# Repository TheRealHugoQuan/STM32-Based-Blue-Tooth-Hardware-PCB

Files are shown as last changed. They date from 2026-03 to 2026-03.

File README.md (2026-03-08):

# 📡 STM32 Bluetooth Low Energy (BLE) Node

## 📖 Overview
This repository contains the complete hardware design files (schematic and PCB layout) for a custom Bluetooth Low Energy (BLE) development board powered by the STM32 architecture. 

Designed specifically for [e.g., low-power IoT applications / wearable prototyping], this board integrates a high-performance ARM Cortex-M core with a 2.4GHz RF radio, optimized power routing, and exposed peripheral headers for rapid sensor integration.

## 🛠️ Hardware Specifications
* **Microcontroller:** [e.g., STM32WB55RG / STM32F4 + External NRF module]
* **Wireless Protocol:** Bluetooth Low Energy (BLE) [e.g., 5.2]
* **Antenna Design:** [e.g., 2.4GHz Meandering PCB Trace Antenna / U.FL connector for external antenna]
* **Clock/Oscillators:** * High-Speed External (HSE): [e.g., 32 MHz crystal for RF timing]
  * Low-Speed External (LSE): [e.g., 32.768 kHz crystal for RTC/Low Power modes]
* **Power Supply:** [e.g., 3.3V LDO regulated from a 5V USB-C input or single Li-Po cell]
* **Programming Interface:** Standard 10-pin SWD (Serial Wire Debug) header
* **Dimensions:** [e.g., 40mm x 25mm]
* **Layers:** [e.g., 4-Layer FR4 with dedicated continuous ground plane for RF shielding]

## 📁 Repository Structure
* `/hardware/` - Core KiCad project files (`.kicad_pro`, `.kicad_sch`, `.kicad_pcb`).
* `/fabrication/` - Exported Gerber files, drill files, and BOM/CPL files ready for PCB assembly (PCBA).
* `/firmware/` - Placeholder or link to the accompanying STM32CubeIDE / Zephyr RTOS software repository.
* `/datasheets/` - Critical component datasheets (MCU, Antenna matching components).

## 🚀 Getting Started
To view or

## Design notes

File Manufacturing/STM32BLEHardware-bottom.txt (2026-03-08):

### Footprint positions - created on 2026-01-26T21:31:32-0500 ###
### Printed by KiCad version 9.0.7
## Unit = mm, Angle = deg.
## Side : bottom
# Ref     Val       Package                PosX       PosY       Rot  Side
## End

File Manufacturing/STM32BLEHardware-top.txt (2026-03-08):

### Footprint positions - created on 2026-01-26T21:31:32-0500 ###
### Printed by KiCad version 9.0.7
## Unit = mm, Angle = deg.
## Side : top
# Ref     Val                          Package                                                       PosX       PosY       Rot  Side
C1        4u7                          C_0603_1608Metric                                          28.2500    12.0250  -90.0000  top
C2        100n                         C_0402_1005Metric                                          30.8000    12.2700  -90.0000  top
C3        100n                         C_0402_1005Metric                                          40.4000    15.6200  -90.0000  top
C4        100n                         C_0402_1005Metric                                          32.6700    20.5500  180.0000  top
C5        100n                         C_0402_1005Metric                                          29.6500    12.2400  -90.0000  top
C6        100n                         C_0402_1005Metric                                          37.8000    10.3700  -90.0000  top
C7        4u7                          C_0603_1608Metric                                          32.0250    23.1000  180.0000  top
C8        100n                         C_0402_1005Metric                                          32.6700    21.7000  180.0000  top
C9        100n                         C_0402_1005Metric                                          40.7000    18.3700  -90.0000  top
C10       4u7                          C_0603_1608Metric                                          37.3750    21.2500    0.0000  top
C11       C                            C_0402_1005Metric                                          32.4000    10.7000  180.0000  top
C12       C                            C_0402_1005Metric                                          34.5000    10.7000    0.0000  top
C13       0p8                          C_0402_1005Metric                                          41.6500    16.3700  -90.0000  top
C14       0p3                          C_0402_1005Metric                                          44.7600    16.4200  -90.0000  top
C15       100n                         C_0402_1005Metric                                          21.3200    10.3500  180.0000  top
C16       100n                         C_0402_1005Metric                                          54.8500    10.1700  -90.0000  top
C17       4u7                          C_0603_1608Metric                                           9.9000    11.3750  -90.0000  top
C18       4u7                          C_0603_1608Metric                                          15.9500    11.4000  -90.0000  top
C19       100n                         C_0402_1005Metric                                          30.2200    16.9000  180.0000  top
D1        LED                          LED_0402_1005Metric                                        30.3150    14.0000    0.0000  top
FID1      Fiducial                     Fiducial_1mm_Mask2mm                                        7.8500     2.4000    0.0000  top
FID2      Fiducial                     Fiducial_1mm_Mask2mm                                       51.2000    23.6000    0.0000  top
FID3      Fiducial                     Fiducial_1mm_Mask2mm                                       51.2000     2.1000    0.0000  top
FLT1      DLF162500LT-5028A1           Untitled                                                   46.5500    16.9300    0.0000  top
J1        Conn_Coaxial                 U.FL_Hirose_U.FL-R-SMT-1_Vertical                          49.8700    16.8000    0.0000  top
J3        USB_C_Receptacle_USB2.0_16P  USB_C_Receptacle_GCT_USB4105-xx-A_16P_TopMnt_Horizontal     4.0600    14.5500  -90.0000  top
J4        Conn_01x04_Pin               Molex_PicoBlade_53048-0410_1x04_P1.25mm_Horizontal         36.9250     4.8000    0.0000  top
L1        10u                          L_0805_2012Metric                                          35.4125    23.0000  180.0000  top
L2        10n                          L_0402_1005Metric                                          34.3500    20.9850   90.0000  top
L3        2n7                          L_0402_1005Metric                                          43.2250    16.8500  180.0000  top
R1        5k1                          R_0402_1005Metric                                          56.0000    10.1400  -90.0000  top
R2        220R                         R_0402_1005Metric                                          53.2400    10.6500    0.0000  top
R3        5k1                          R_0402_1005Metric                                           6.9600     8.5000    0.0000  top
R4        5k1                          R_0402_1005Metric                                           7.6500    20.9000  180.0000  top
R5        220R                         R_0402_1005Metric                                          39.0000    10.3400  -90.0000  top
R6        220R                         R_0402_1005Metric                                          40.1000    10.3400  -90.0000  top
R7        220R                         R_0402_1005Metric                                          28.0400    14.2000  180.0000  top
SW1       SW_Push                      SW_SPST_CK_RS282G05A3                                      47.2000    10.7000    0.0000  top
U1        STM32WB55CEU6                QFN-48-1EP_7x7mm_P0.5mm_EP5.6x5.6mm                        35.6000    15.6500   90.0000  top
U2        USBLC6-2SC6(ESD)             SOT-23-6                                                   13.8125    18.7000    0.0000  top
U3        MIC5365-3.3YD5               TSOT-23-5                                                  13.0125    11.2500    0.0000  top
Y1        32MHz                        Crystal_SMD_2016-4Pin_2.0x1.6mm                            40.8000    21.4000   90.0000  top
Y2        32kHz768                     Crystal_SMD_2012-2Pin_2.0x1.2mm                            33.1000     8.3500    0.0000  top
## End

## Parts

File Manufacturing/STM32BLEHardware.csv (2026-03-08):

Reference | Qty | Value | DNP | Exclude from BOM | Exclude from Board | Footprint | Datasheet | Manufacturer | Manufacturer Part No. | Link
C1,C7,C10,C17,C18 | 5 | 4u7 |  |  |  | Capacitor_SMD:C_0603_1608Metric | ~ | KYOCERA AVX | 0603ZD475KAT2A | https://www.google.com/search
C2,C3,C4,C5,C6,C8,C9,C15,C16,C19 | 10 | 100n |  |  |  | Capacitor_SMD:C_0402_1005Metric | ~ | KYOCERA AVX | VX 0402ZC104KAT2A | https://www.google.com/search
C11,C12 | 2 | C |  |  |  | Capacitor_SMD:C_0402_1005Metric | ~ | KYOCERA AVX | 04025A120JAT2A | https://www.google.com/search
C13 | 1 | 0p8 |  |  |  | Capacitor_SMD:C_0402_1005Metric | ~ | Murata | GJM1555C1HR80WB01D | https://www.google.com/search
C14 | 1 | 0p3 |  |  |  | Capacitor_SMD:C_0402_1005Metric | ~ | Murata | GJM1555C1HR30WB01D | https://www.google.com/search
D1 | 1 | LED |  |  |  | LED_SMD:LED_0402_1005Metric | ~ | Wurth Elektronik | 150040GS73220 | https://www.google.com/search
FID1,FID2,FID3 | 3 | Fiducial |  | Excluded from BOM |  | Fiducial:Fiducial_1mm_Mask2mm | ~
FLT1 | 1 | DLF162500LT-5028A1 |  |  |  | myFootPrint:Untitled |  | TDK | DLF162500LT-5028A1 | https://www.google.com/search?q=https://www.mouser.com/ProductDetail/TDK/DLF162500LT-5028A1
H1,H2,H3,H4 | 4 | MountingHole_Pad |  | Excluded from BOM |  | MountingHole:MountingHole_2.2mm_M2_Pad_Via | ~
J1 | 1 | Conn_Coaxial |  |  |  | Connector_Coaxial:U.FL_Hirose_U.FL-R-SMT-1_Vertical | ~ | Hirose | U.FL-R-SMT-1(10) | https://www.google.com/search
J2 | 1 | Conn_ARM_SWD_TagConnect_TC2030 |  | Excluded from BOM |  | Connector:Tag-Connect_TC2030-IDC-FP_2x03_P1.27mm_Vertical | https://www.tag-connect.com/wp-content/uploads/bsk-pdf-manager/TC2030-CTX_1.pdf | Tag-Connect | TC2030-IDC-NL (Cable) | https://www.tag-connect.com/product/tc2030-idc-nl
J3 | 1 | USB_C_Receptacle_USB2.0_16P |  |  |  | Connector_USB:USB_C_Receptacle_GCT_USB4105-xx-A_16P_TopMnt_Horizontal | https://www.usb.org/sites/default/files/documents/usb_type-c.zip | GCT | USB4105-GF-A | https://www.google.com/search
J4 | 1 | Conn_01x04_Pin |  |  |  | Connector_Molex:Molex_PicoBlade_53048-0410_1x04_P1.25mm_Horizontal | ~ | Molex | 53048-0410 | https://www.google.com/search?q=https://www.digikey.com/en/products/detail/molex/0530480410/252975
L1 | 1 | 10u |  |  |  | Inductor_SMD:L_0805_2012Metric | ~ | Murata | LQM21PN100MGR | https://www.google.com/search
L2 | 1 | 10n |  |  |  | Inductor_SMD:L_0402_1005Metric | ~ | Murata | LQG15HS10NJ02D | https://www.google.com/search
L3 | 1 | 2n7 |  |  |  | Inductor_SMD:L_0402_1005Metric | ~ | Murata | LQG15HS2N7S02D | https://www.google.com/search
R1,R3,R4 | 3 | 5k1 |  |  |  | Resistor_SMD:R_0402_1005Metric | ~ | Yageo | RC0402JR-075K1L | https://www.google.com/search
R2,R5,R6,R7 | 4 | 220R |  |  |  | Resistor_SMD:R_0402_1005Metric | ~ | Yageo | RC0402JR-07220RL | https://www.google.com/search
SW1 | 1 | SW_Push |  |  |  | Button_Switch_SMD:SW_SPST_CK_RS282G05A3 | ~ | C&K | RS-282G05A3-SM RT | https://www.google.com/search
U1 | 1 | STM32WB55CEU6 |  |  |  | Package_DFN_QFN:QFN-48-1EP_7x7mm_P0.5mm_EP5.6x5.6mm | https://www.st.com/resource/en/datasheet/stm32wb55ce.pdf | STMicroelectronics | STM32WB55CEU6 | https://www.google.com/search
U2 | 1 | USBLC6-2SC6(ESD) |  |  |  | Package_TO_SOT_SMD:SOT-23-6 | https://www.st.com/resource/en/datasheet/usblc6-2.pdf | STMicroelectronics | USBLC6-2SC6 | https://www.digikey.com/en/products/detail/microchip-technology/MIC5365-3-3YD5-TR/3671879
U3 | 1 | MIC5365-3.3YD5 |  |  |  | Package_TO_SOT_SMD:TSOT-23-5 | https://ww1.microchip.com/downloads/aemDocuments/documents/APID/ProductDocuments/DataSheets/MIC5365-6-High-Performance-Single-150mA-LDO-DS20006605A.pdf | Microchip | MIC5365-3.3YD5-TR | https://www.digikey.com/en/products/detail/microchip-technology/MIC5365-3-3YD5-TR/3671879
Y1 | 1 | 32MHz |  |  |  | Crystal:Crystal_SMD_2016-4Pin_2.0x1.6mm | ~ | NDK | NX2016SA-32M-EXS00A-CS06465 | https://www.google.com/search
Y2 | 1 | 32kHz768 |  |  |  | Crystal:Crystal_SMD_2012-2Pin_2.0x1.2mm | ~ | NDK | NX2012SA-32.768K-STD-MUB-1 | https://www.google.com/search

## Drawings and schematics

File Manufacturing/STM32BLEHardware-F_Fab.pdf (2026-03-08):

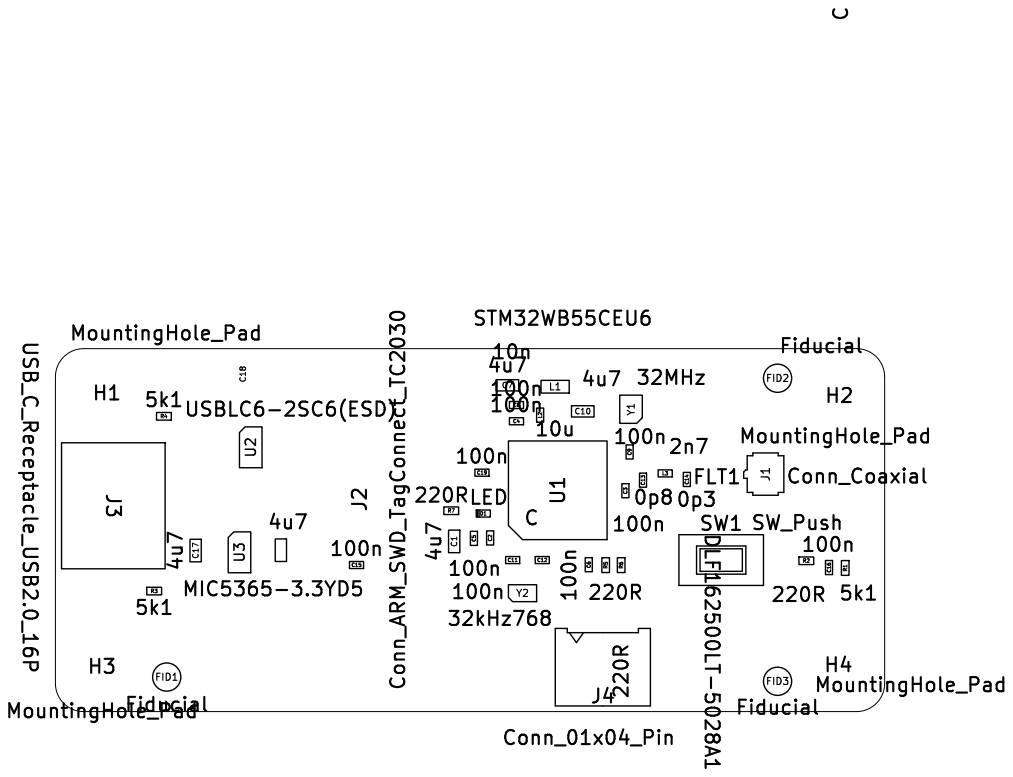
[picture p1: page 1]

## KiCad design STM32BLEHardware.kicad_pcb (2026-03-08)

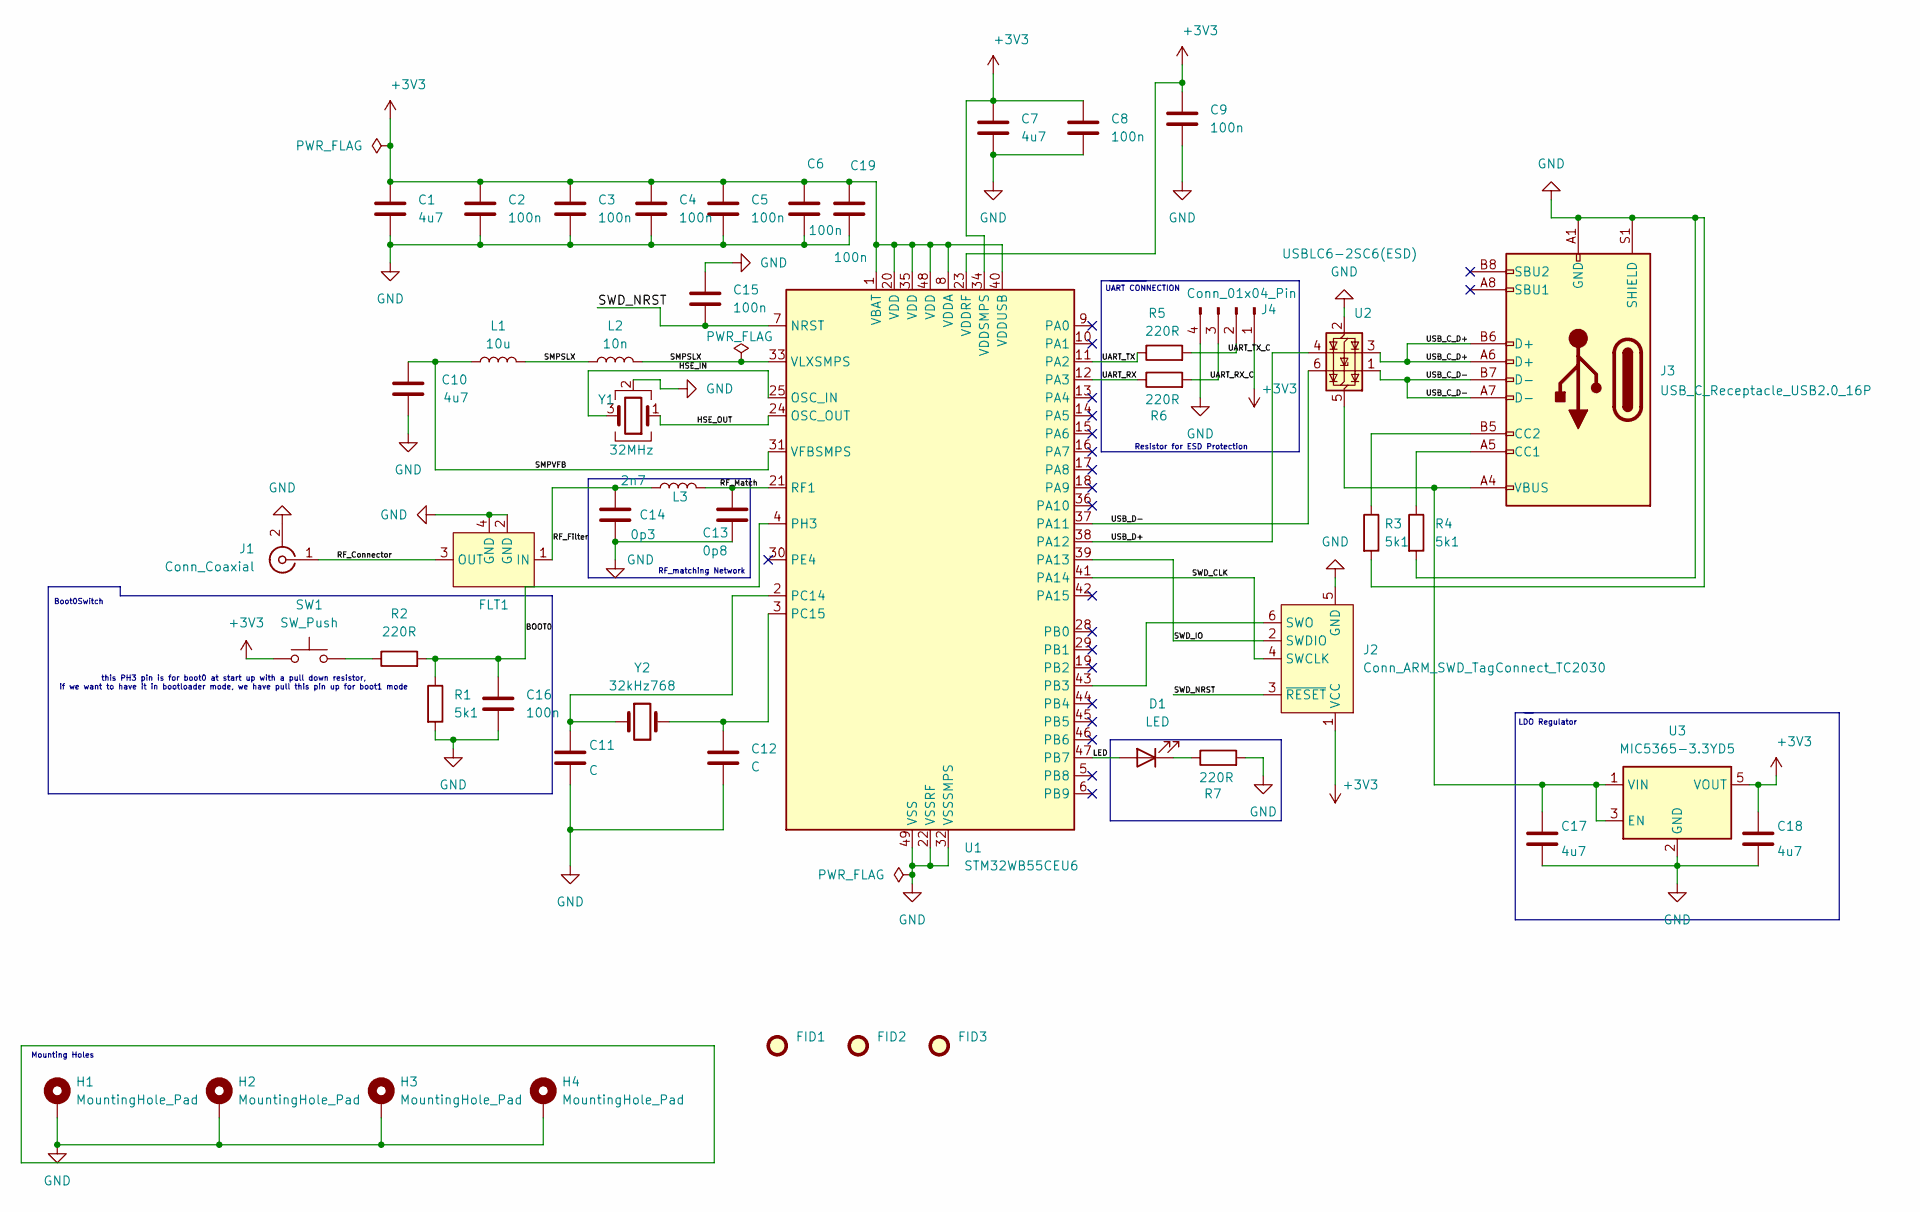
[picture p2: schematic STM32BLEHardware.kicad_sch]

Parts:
C1, C7, C10, C17, C18: 4u7; C_0603_1608Metric; Manufacturer Part No. 0603ZD475KAT2A
C2, C3, C4, C5, C6, C8, C9, C15, C16, C19: 100n; C_0402_1005Metric; Manufacturer Part No. VX 0402ZC104KAT2A
C11, C12: C; C_0402_1005Metric; Manufacturer Part No. 04025A120JAT2A
C13: 0p8; C_0402_1005Metric; Manufacturer Part No. GJM1555C1HR80WB01D
C14: 0p3; C_0402_1005Metric; Manufacturer Part No. GJM1555C1HR30WB01D
D1: LED; LED_0402_1005Metric; Manufacturer Part No. 150040GS73220
FID1, FID2, FID3: Fiducial; Fiducial_1mm_Mask2mm
FLT1: DLF162500LT-5028A1; Untitled; Manufacturer Part No. DLF162500LT-5028A1
H1, H2, H3, H4: MountingHole_Pad; MountingHole_2.2mm_M2_Pad_Via
J1: Conn_Coaxial; U.FL_Hirose_U.FL-R-SMT-1_Vertical; Manufacturer Part No. U.FL-R-SMT-1(10)
J2: Conn_ARM_SWD_TagConnect_TC2030; Tag-Connect_TC2030-IDC-FP_2x03_P1.27mm_Vertical; Manufacturer Part No. TC2030-IDC-NL (Cable)
J3: USB_C_Receptacle_USB2.0_16P; USB_C_Receptacle_GCT_USB4105-xx-A_16P_TopMnt_Horizontal; Manufacturer Part No. USB4105-GF-A
J4: Conn_01x04_Pin; Molex_PicoBlade_53048-0410_1x04_P1.25mm_Horizontal; Manufacturer Part No. 53048-0410
L1: 10u; L_0805_2012Metric; Manufacturer Part No. LQM21PN100MGR
L2: 10n; L_0402_1005Metric; Manufacturer Part No. LQG15HS10NJ02D
L3: 2n7; L_0402_1005Metric; Manufacturer Part No. LQG15HS2N7S02D
R1, R3, R4: 5k1; R_0402_1005Metric; Manufacturer Part No. RC0402JR-075K1L
R2, R5, R6, R7: 220R; R_0402_1005Metric; Manufacturer Part No. RC0402JR-07220RL
SW1: SW_Push; SW_SPST_CK_RS282G05A3; Manufacturer Part No. RS-282G05A3-SM RT
U1: STM32WB55CEU6; QFN-48-1EP_7x7mm_P0.5mm_EP5.6x5.6mm; Manufacturer Part No. STM32WB55CEU6
U2: USBLC6-2SC6(ESD); SOT-23-6; Manufacturer Part No. USBLC6-2SC6
U3: MIC5365-3.3YD5; TSOT-23-5; Manufacturer Part No. MIC5365-3.3YD5-TR
Y1: 32MHz; Crystal_SMD_2016-4Pin_2.0x1.6mm; Manufacturer Part No. NX2016SA-32M-EXS00A-CS06465
Y2: 32kHz768; Crystal_SMD_2012-2Pin_2.0x1.2mm; Manufacturer Part No. NX2012SA-32.768K-STD-MUB-1

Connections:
+3V3: C1.1, C2.1, C3.1, C4.1, C5.1, C6.1, C7.1, C8.1, C9.1, C18.1, C19.1, J2.1 (VCC), J4.1, SW1.1, U1.1 (VBAT), U1.8 (VDDA), U1.20 (VDD), U1.23 (VDDRF), U1.34 (VDDSMPS), U1.35 (VDD), U1.40 (VDDUSB), U1.48 (VDD), U3.5 (VOUT)
/BOOT0: C16.1, R1.1, R2.2, U1.4 (PH3)
/HSE_IN: U1.25 (OSC_IN), Y1.3
/HSE_OUT: U1.24 (OSC_OUT), Y1.1
/LED: D1.2 (A), U1.47 (PB7)
/RF_Connector: FLT1.3 (OUT), J1.1 (In)
/RF_Filter: C14.1, FLT1.1 (IN), L3.1
/RF_Match: C13.1, L3.2, U1.21 (RF1)
/SMPSLX: L1.2, L2.1, L2.2, U1.33 (VLXSMPS)
/SMPVFB: C10.1, L1.1, U1.31 (VFBSMPS)
/SWD_CLK: J2.4 (SWCLK), U1.41 (PA14)
/SWD_IO: J2.2 (SWDIO), U1.39 (PA13)
/SWD_NRST: C15.2, J2.3 (~RESET), U1.7 (NRST)
/UART_RX: R6.1, U1.12 (PA3)
/UART_RX_C: J4.3, R6.2
/UART_TX: R5.1, U1.11 (PA2)
/UART_TX_C: J4.2, R5.2
/USB_C_D+: J3.A6 (D+), J3.B6 (D+), U2.3 (I/O2)
/USB_C_D-: J3.A7 (D-), J3.B7 (D-), U2.1 (I/O1)
/USB_D+: U1.38 (PA12), U2.4 (I/O2)
/USB_D-: U1.37 (PA11), U2.6 (I/O1)
GND: C1.2, C2.2, C3.2, C4.2, C5.2, C6.2, C7.2, C8.2, C9.2, C10.2, C11.2, C12.2, C13.2, C14.2, C15.1, C16.2, C17.2, C18.2, C19.2, FLT1.2 (GND), FLT1.4 (GND), H1.1, H2.1, H3.1, H4.1, J1.2 (Ext), J2.5 (GND), J3.A1 (GND), J3.A12 (GND), J3.B1 (GND), J3.B12 (GND), J3.S1 (SHIELD), J4.4, R1.2, R3.2, R4.2, R7.2, U1.22 (VSSRF), U1.32 (VSSSMPS), U1.49 (VSS), U2.2 (GND), U3.2 (GND), Y1.2 (G), Y1.4 (G)
unnamed: D1.1 (K), R7.1
unnamed: J2.6 (SWO), U1.43 (PB3)
unnamed: J3.A5 (CC1), R4.1
unnamed: J3.B5 (CC2), R3.1
unnamed: R2.1, SW1.2
unnamed: C11.1, U1.2 (PC14), Y2.1
unnamed: C12.1, U1.3 (PC15), Y2.2
unnamed: C17.1, J3.A4 (VBUS), J3.A9 (VBUS), J3.B4 (VBUS), J3.B9 (VBUS), U2.5 (VBUS), U3.1 (VIN), U3.3 (EN)

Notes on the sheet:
UART CONNECTION
LDO Regulator
Resistor for ESD Protection
Boot0Switch
RF_matching Network
this PH3 pin is for boot0 at start up with a pull down resistor, if we want to have it in bootloader mode, we have pull this pin up for boot1 mode
Mounting Holes

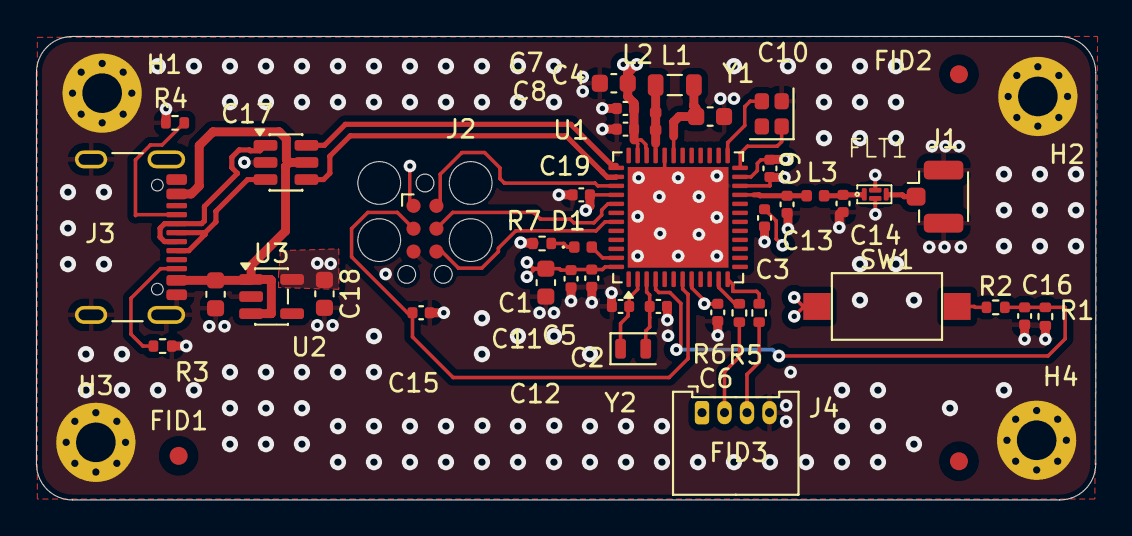
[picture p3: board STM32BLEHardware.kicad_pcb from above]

Board: 4 copper layers, 58.8 x 25.8 mm, 48 parts (0 on the bottom side), 30 nets.

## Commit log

2026-03-08 first revision files
    [STM32BLEHardware-B_Cu.gbr, STM32BLEHardware-B_Mask.gbr, STM32BLEHardware-B_Paste.gbr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]
2026-03-08 Initialize README with project details and specifications
    Added detailed overview, hardware specifications, and repository structure for the STM32 BLE Node project.
2026-03-08 Remove schematic and board layout section
    Removed schematic and board layout section from README.
